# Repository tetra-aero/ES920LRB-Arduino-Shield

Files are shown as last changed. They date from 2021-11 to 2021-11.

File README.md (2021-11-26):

# ES920LRB-Arduino-Shield
Arduino Shield for ES920LRB (EASEL), Private LoRa module
- https://easel5.com/service/products-information/products/wireless-module/es920lr2/
- https://easel5.com/documents/files/ES920LR2%E3%83%87%E3%83%BC%E3%82%BF%E3%82%B7%E3%83%BC%E3%83%88_1.04.pdf
- https://easel5.com/documents/files/ES920LRB_BASE%E5%9F%BA%E6%9D%BF%E5%AF%B8%E6%B3%95%E5%9B%B3.pdf

### Ref.
1. https://ambidata.io/samples/network/lora-2/
2. https://qiita.com/nbizyc/items/6f2346ffbe005a5345e9
3. https://github.com/AmbientDataInc/LoRa-rssi-measure

## Schematic, PCB
- Arduino UNO
    - https://github.com/tetra-aero/ES920LRB-Arduino-Shield/tree/main/ES920LRB-Arduino_Uno-Shield
- ESP32 (not shield)
    - https://github.com/tetra-aero/ES920LRB-Arduino-Shield/tree/main/ES920LRB-ESP32

## Firmware
- Arduino UNO, PlatformIO
    - https://github.com/tetra-aero/ES920LRB-Arduino-Shield/tree/main/ES920LRB-Arduino_Uno-Shield/ES920LR-Arduino-PIO
- ESP32, PlatformIO
    - https://github.com/tetra-aero/ES920LRB-Arduino-Shield/tree/main/ES920LRB-ESP32/ESP920LR-Coordinator-ESP32-PIO
    - https://github.com/tetra-aero/ES920LRB-Arduino-Shield/tree/main/ES920LRB-ESP32/ESP920LR-End-device-ESP32-PIO

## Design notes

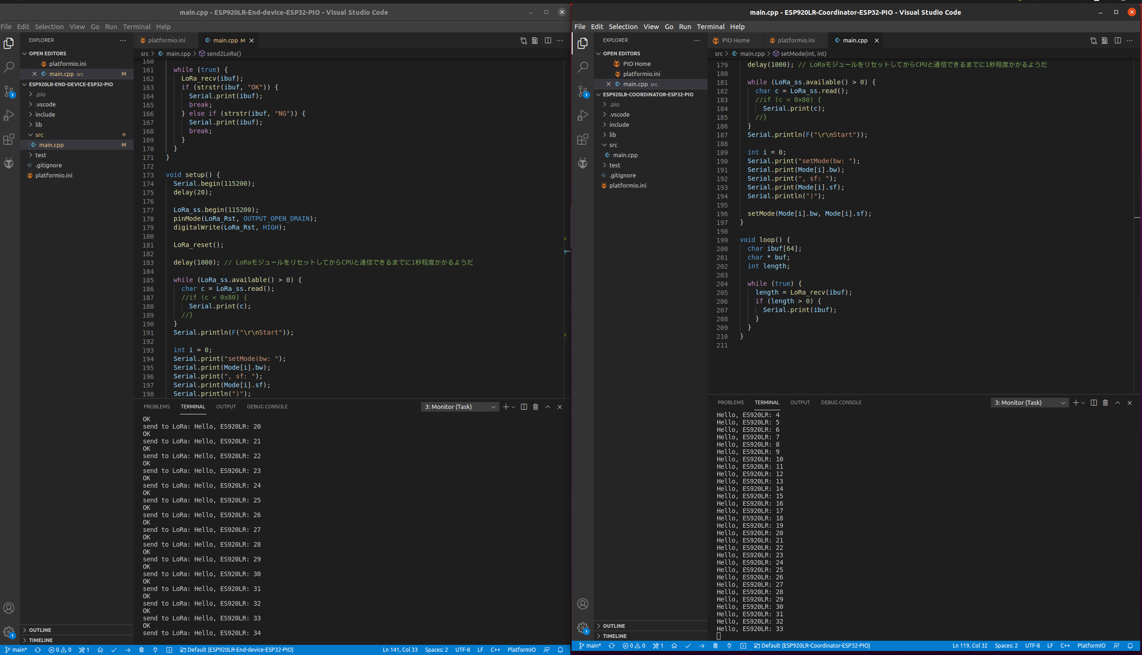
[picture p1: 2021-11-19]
document/211120_esp32_count_success.png

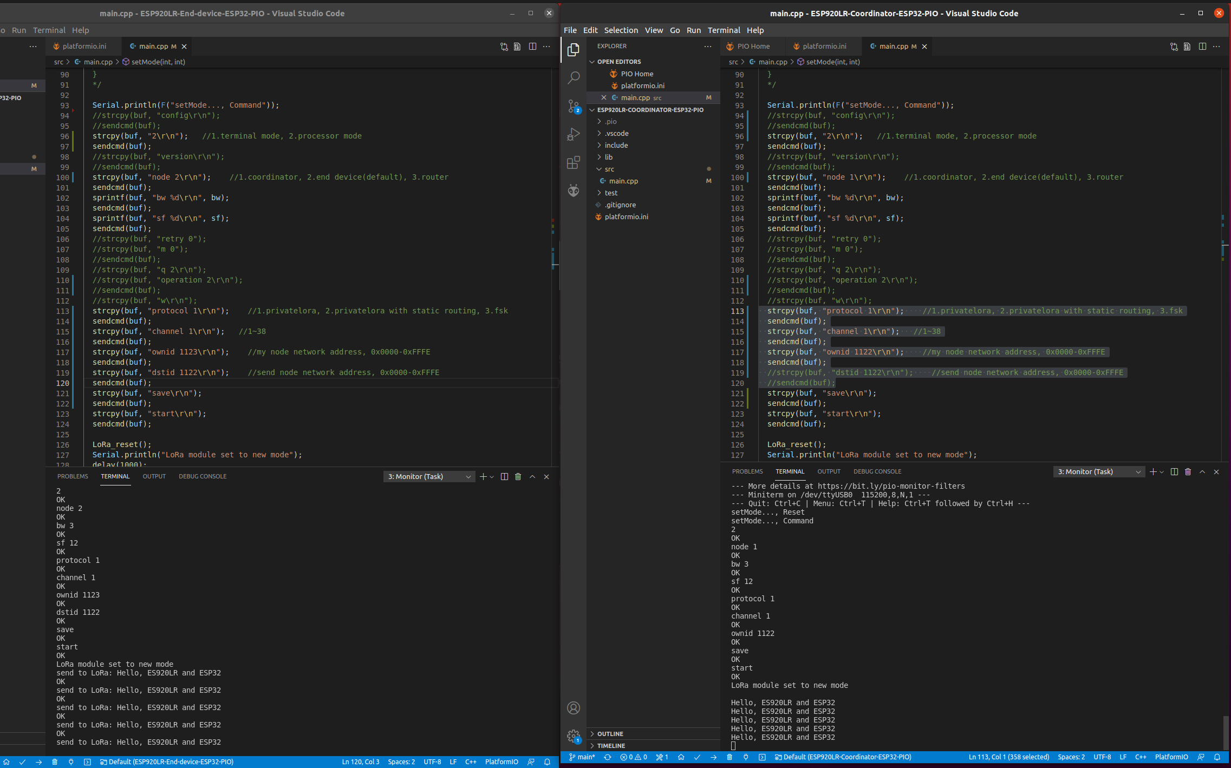
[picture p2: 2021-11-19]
document/211120_esp32_transmission_success.png

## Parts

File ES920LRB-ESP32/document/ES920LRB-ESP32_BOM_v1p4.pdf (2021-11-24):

ES920LRB-ESP32_BOM_v1p4

Source:
Date:
Tool:
Generator:
Component Count:

Collated Components:

Item
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
/home/chiya/JetsonWorks/ES920LRB-Arduino-Shield/ES920LRB-ESP32/ES920LRB-ESP32.sch Wed 24 Nov 2021 08:32:15 PM JST
Eeschema 5.1.9-73d0e3b20d~88~ubuntu20.04.1 /usr/share/kicad/plugins/bom_csv_grouped_by_value.py
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
Reference(s) | Value | LibPart
C1, C2 | 10uF | Device:C
H1, H2, H3, H4 | MountingHole | Mechanical:MountingHole
J1, J2 | Conn_01x19_Female Connector:Conn_01x19_Female
J3, J4 | Conn_01x13_Female Connector:Conn_01x13_Female
L1 | Logo | teTra:Logo
M1 | ES920LR2B | teTra:ES920LR2B
R1, R2, R3, R4, R5, R6 10k | Device:R
U1 | ESP32-DEVKITC-32D ESP32_32D_module:ESP32-DEVKITC-32D

Footprint | Datasheet | Field4
Capacitor_THT:C_Rect_L4.0mm_W2.5mm_P2.50mm | ~
MountingHole:MountingHole_3.2mm_M3 | ~
Connector_PinHeader_2.54mm:PinHeader_1x19_P2.54mm_Vertical | ~
Connector_PinHeader_2.54mm:PinHeader_1x13_P2.54mm_Vertical | ~
teTra:teTra-logo
teTra:ES92LR2B
Resistor_THT:R_Axial_DIN0207_L6.3mm_D2.5mm_P7.62mm_Horizontal ~
MODULE_ESP32-DEVKITC-32D | Espressif Systems | 4

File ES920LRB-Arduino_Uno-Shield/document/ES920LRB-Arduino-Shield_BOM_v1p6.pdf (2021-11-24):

ES920LRB-Arduino-Shield_BOM_v1p6

Source:
Date:
Tool:
Generator:
Component Count:

Collated Components:

Item
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
/home/chiya/JetsonWorks/ES920LRB-Arduino-Shield/ES920LRB-Arduino-Shield/ES920LRB-Arduino-Shield.sch Wed 24 Nov 2021 06:48:10 PM JST
Eeschema 5.1.9-73d0e3b20d~88~ubuntu20.04.1 /usr/share/kicad/plugins/bom_csv_grouped_by_value.py
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
Reference(s) | Value | LibPart
C1 | 10uF | Device:C
J1 | Conn_01x10_Female | Connector:Conn_01x10_Female
J2 | Conn_01x12_Female | Connector:Conn_01x12_Female
JP1, JP2, JP3, JP4, JP5, JP6 | SolderJumper_2_Open Jumper:SolderJumper_2_Open
L1 | Logo | teTra:Logo
M1 | ES920LR2B | teTra:ES920LR2B
P1 | Power | Connector_Generic:Conn_01x08
P2 | Analog | Connector_Generic:Conn_01x06
P3 | Digital | Connector_Generic:Conn_01x10
P4 | Digital | Connector_Generic:Conn_01x08
P5, P6, P7, P8 | CONN_01X01 | Connector_Generic:Conn_01x01
Q1, Q2, Q3, Q4 | BSS138 | add_lib2:BSS138
R1, R2, R3, R4, R5, R6, R7, R8, R9, R10 10k | Device:R

Footprint
Capacitor_THT:C_Rect_L4.0mm_W2.5mm_P2.50mm Connector_PinHeader_2.54mm:PinHeader_1x10_P2.54mm_Vertical Connector_PinHeader_2.54mm:PinHeader_1x12_P2.54mm_Vertical Jumper:SolderJumper-2_P1.3mm_Open_Pad1.0x1.5mm teTra:teTra-logo
teTra:ES92LR2B
Socket_Arduino_Uno:Socket_Strip_Arduino_1x08 Socket_Arduino_Uno:Socket_Strip_Arduino_1x06 Socket_Arduino_Uno:Socket_Strip_Arduino_1x10 Socket_Arduino_Uno:Socket_Strip_Arduino_1x08 Socket_Arduino_Uno:Arduino_1pin
Package_TO_SOT_SMD:SOT-23
Resistor_THT:R_Axial_DIN0207_L6.3mm_D2.5mm_P2.54mm_Vertical

Datasheet
~
~
~
~

Replace 1.27mm pitch, 3.0mm height, pin socket x2

https://www.onsemi.com/pub/Collateral/BSS138-D.PDF ~

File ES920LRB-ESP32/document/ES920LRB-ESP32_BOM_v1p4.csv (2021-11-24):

Source: | /home/chiya/JetsonWorks/ES920LRB-Arduino-Shield/ES920LRB-ESP32/ES920LRB-ESP32.sch
Date: | Wed 24 Nov 2021 08:32:15 PM JST
Tool: | Eeschema 5.1.9-73d0e3b20d~88~ubuntu20.04.1
Generator: | /usr/share/kicad/plugins/bom_csv_grouped_by_value.py
Component Count: | 19
Individual Components:
Item | Qty | Reference(s) | Value | LibPart | Footprint | Datasheet | Field4
 |  | C1 | 10uF | Device:C | Capacitor_THT:C_Rect_L4.0mm_W2.5mm_P2.50mm | ~
 |  | C2 | 10uF | Device:C | Capacitor_THT:C_Rect_L4.0mm_W2.5mm_P2.50mm | ~
 |  | H1 | MountingHole | Mechanical:MountingHole | MountingHole:MountingHole_3.2mm_M3 | ~
 |  | H2 | MountingHole | Mechanical:MountingHole | MountingHole:MountingHole_3.2mm_M3 | ~
 |  | H3 | MountingHole | Mechanical:MountingHole | MountingHole:MountingHole_3.2mm_M3 | ~
 |  | H4 | MountingHole | Mechanical:MountingHole | MountingHole:MountingHole_3.2mm_M3 | ~
 |  | J1 | Conn_01x19_Female | Connector:Conn_01x19_Female | Connector_PinHeader_2.54mm:PinHeader_1x19_P2.54mm_Vertical | ~
 |  | J2 | Conn_01x19_Female | Connector:Conn_01x19_Female | Connector_PinHeader_2.54mm:PinHeader_1x19_P2.54mm_Vertical | ~
 |  | J3 | Conn_01x13_Female | Connector:Conn_01x13_Female | Connector_PinHeader_2.54mm:PinHeader_1x13_P2.54mm_Vertical | ~
 |  | J4 | Conn_01x13_Female | Connector:Conn_01x13_Female | Connector_PinHeader_2.54mm:PinHeader_1x13_P2.54mm_Vertical | ~
 |  | L1 | Logo | teTra:Logo | teTra:teTra-logo
 |  | M1 | ES920LR2B | teTra:ES920LR2B | teTra:ES92LR2B
 |  | R1 | 10k | Device:R | Resistor_THT:R_Axial_DIN0207_L6.3mm_D2.5mm_P7.62mm_Horizontal | ~
 |  | R2 | 10k | Device:R | Resistor_THT:R_Axial_DIN0207_L6.3mm_D2.5mm_P7.62mm_Horizontal | ~
 |  | R3 | 10k | Device:R | Resistor_THT:R_Axial_DIN0207_L6.3mm_D2.5mm_P7.62mm_Horizontal | ~
 |  | R4 | 10k | Device:R | Resistor_THT:R_Axial_DIN0207_L6.3mm_D2.5mm_P7.62mm_Horizontal | ~
 |  | R5 | 10k | Device:R | Resistor_THT:R_Axial_DIN0207_L6.3mm_D2.5mm_P7.62mm_Horizontal | ~
 |  | R6 | 10k | Device:R | Resistor_THT:R_Axial_DIN0207_L6.3mm_D2.5mm_P7.62mm_Horizontal | ~
 |  | U1 | ESP32-DEVKITC-32D | ESP32_32D_module:ESP32-DEVKITC-32D | MODULE_ESP32-DEVKITC-32D | Espressif Systems | 4
Collated Components:
Item | Qty | Reference(s) | Value | LibPart | Footprint | Datasheet | Field4
1 | 2 | C1, C2 | 10uF | Device:C | Capacitor_THT:C_Rect_L4.0mm_W2.5mm_P2.50mm | ~
2 | 4 | H1, H2, H3, H4 | MountingHole | Mechanical:MountingHole | MountingHole:MountingHole_3.2mm_M3 | ~
3 | 2 | J1, J2 | Conn_01x19_Female | Connector:Conn_01x19_Female | Connector_PinHeader_2.54mm:PinHeader_1x19_P2.54mm_Vertical | ~
4 | 2 | J3, J4 | Conn_01x13_Female | Connector:Conn_01x13_Female | Connector_PinHeader_2.54mm:PinHeader_1x13_P2.54mm_Vertical | ~
5 | 1 | L1 | Logo | teTra:Logo | teTra:teTra-logo
6 | 1 | M1 | ES920LR2B | teTra:ES920LR2B | teTra:ES92LR2B
7 | 6 | R1, R2, R3, R4, R5, R6 | 10k | Device:R | Resistor_THT:R_Axial_DIN0207_L6.3mm_D2.5mm_P7.62mm_Horizontal | ~
8 | 1 | U1 | ESP32-DEVKITC-32D | ESP32_32D_module:ESP32-DEVKITC-32D | MODULE_ESP32-DEVKITC-32D | Espressif Systems | 4

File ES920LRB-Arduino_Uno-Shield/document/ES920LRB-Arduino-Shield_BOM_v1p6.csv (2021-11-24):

Source: | /home/chiya/JetsonWorks/ES920LRB-Arduino-Shield/ES920LRB-Arduino-Shield/ES920LRB-Arduino-Shield.sch
Date: | Wed 24 Nov 2021 06:48:10 PM JST
Tool: | Eeschema 5.1.9-73d0e3b20d~88~ubuntu20.04.1
Generator: | /usr/share/kicad/plugins/bom_csv_grouped_by_value.py
Component Count: | 33
Individual Components:
Item | Qty | Reference(s) | Value | LibPart | Footprint | Datasheet
 |  | C1 | 10uF | Device:C | Capacitor_THT:C_Rect_L4.0mm_W2.5mm_P2.50mm | ~
 |  | J1 | Conn_01x10_Female | Connector:Conn_01x10_Female | Connector_PinHeader_2.54mm:PinHeader_1x10_P2.54mm_Vertical | ~
 |  | J2 | Conn_01x12_Female | Connector:Conn_01x12_Female | Connector_PinHeader_2.54mm:PinHeader_1x12_P2.54mm_Vertical | ~
 |  | JP1 | SolderJumper_2_Open | Jumper:SolderJumper_2_Open | Jumper:SolderJumper-2_P1.3mm_Open_Pad1.0x1.5mm | ~
 |  | JP2 | SolderJumper_2_Open | Jumper:SolderJumper_2_Open | Jumper:SolderJumper-2_P1.3mm_Open_Pad1.0x1.5mm | ~
 |  | JP3 | SolderJumper_2_Open | Jumper:SolderJumper_2_Open | Jumper:SolderJumper-2_P1.3mm_Open_Pad1.0x1.5mm | ~
 |  | JP4 | SolderJumper_2_Open | Jumper:SolderJumper_2_Open | Jumper:SolderJumper-2_P1.3mm_Open_Pad1.0x1.5mm | ~
 |  | JP5 | SolderJumper_2_Open | Jumper:SolderJumper_2_Open | Jumper:SolderJumper-2_P1.3mm_Open_Pad1.0x1.5mm | ~
 |  | JP6 | SolderJumper_2_Open | Jumper:SolderJumper_2_Open | Jumper:SolderJumper-2_P1.3mm_Open_Pad1.0x1.5mm | ~
 |  | L1 | Logo | teTra:Logo | teTra:teTra-logo
 |  | M1 | ES920LR2B | teTra:ES920LR2B | teTra:ES92LR2B
 |  | P1 | Power | Connector_Generic:Conn_01x08 | Socket_Arduino_Uno:Socket_Strip_Arduino_1x08
 |  | P2 | Analog | Connector_Generic:Conn_01x06 | Socket_Arduino_Uno:Socket_Strip_Arduino_1x06
 |  | P3 | Digital | Connector_Generic:Conn_01x10 | Socket_Arduino_Uno:Socket_Strip_Arduino_1x10
 |  | P4 | Digital | Connector_Generic:Conn_01x08 | Socket_Arduino_Uno:Socket_Strip_Arduino_1x08
 |  | P5 | CONN_01X01 | Connector_Generic:Conn_01x01 | Socket_Arduino_Uno:Arduino_1pin
 |  | P6 | CONN_01X01 | Connector_Generic:Conn_01x01 | Socket_Arduino_Uno:Arduino_1pin
 |  | P7 | CONN_01X01 | Connector_Generic:Conn_01x01 | Socket_Arduino_Uno:Arduino_1pin
 |  | P8 | CONN_01X01 | Connector_Generic:Conn_01x01 | Socket_Arduino_Uno:Arduino_1pin
 |  | Q1 | BSS138 | add_lib2:BSS138 | Package_TO_SOT_SMD:SOT-23 | https://www.onsemi.com/pub/Collateral/BSS138-D.PDF
 |  | Q2 | BSS138 | add_lib2:BSS138 | Package_TO_SOT_SMD:SOT-23 | https://www.onsemi.com/pub/Collateral/BSS138-D.PDF
 |  | Q3 | BSS138 | add_lib2:BSS138 | Package_TO_SOT_SMD:SOT-23 | https://www.onsemi.com/pub/Collateral/BSS138-D.PDF
 |  | Q4 | BSS138 | add_lib2:BSS138 | Package_TO_SOT_SMD:SOT-23 | https://www.onsemi.com/pub/Collateral/BSS138-D.PDF
 |  | R1 | 10k | Device:R | Resistor_THT:R_Axial_DIN0207_L6.3mm_D2.5mm_P2.54mm_Vertical | ~
 |  | R2 | 10k | Device:R | Resistor_THT:R_Axial_DIN0207_L6.3mm_D2.5mm_P2.54mm_Vertical | ~
 |  | R3 | 10k | Device:R | Resistor_THT:R_Axial_DIN0207_L6.3mm_D2.5mm_P2.54mm_Vertical | ~
 |  | R4 | 10k | Device:R | Resistor_THT:R_Axial_DIN0207_L6.3mm_D2.5mm_P2.54mm_Vertical | ~
 |  | R5 | 10k | Device:R | Resistor_THT:R_Axial_DIN0207_L6.3mm_D2.5mm_P2.54mm_Vertical | ~
 |  | R6 | 10k | Device:R | Resistor_THT:R_Axial_DIN0207_L6.3mm_D2.5mm_P2.54mm_Vertical | ~
 |  | R7 | 10k | Device:R | Resistor_THT:R_Axial_DIN0207_L6.3mm_D2.5mm_P2.54mm_Vertical | ~
 |  | R8 | 10k | Device:R | Resistor_THT:R_Axial_DIN0207_L6.3mm_D2.5mm_P2.54mm_Vertical | ~
 |  | R9 | 10k | Device:R | Resistor_THT:R_Axial_DIN0207_L6.3mm_D2.5mm_P2.54mm_Vertical | ~
 |  | R10 | 10k | Device:R | Resistor_THT:R_Axial_DIN0207_L6.3mm_D2.5mm_P2.54mm_Vertical | ~
Collated Components:
Item | Qty | Reference(s) | Value | LibPart | Footprint | Datasheet
1 | 1 | C1 | 10uF | Device:C | Capacitor_THT:C_Rect_L4.0mm_W2.5mm_P2.50mm | ~
2 | 1 | J1 | Conn_01x10_Female | Connector:Conn_01x10_Female | Connector_PinHeader_2.54mm:PinHeader_1x10_P2.54mm_Vertical | ~
3 | 1 | J2 | Conn_01x12_Female | Connector:Conn_01x12_Female | Connector_PinHeader_2.54mm:PinHeader_1x12_P2.54mm_Vertical | ~
4 | 6 | JP1, JP2, JP3, JP4, JP5, JP6 | SolderJumper_2_Open | Jumper:SolderJumper_2_Open | Jumper:SolderJumper-2_P1.3mm_Open_Pad1.0x1.5mm | ~
5 | 1 | L1 | Logo | teTra:Logo | teTra:teTra-logo
6 | 1 | M1 | ES920LR2B | teTra:ES920LR2B | teTra:ES92LR2B
7 | 1 | P1 | Power | Connector_Generic:Conn_01x08 | Socket_Arduino_Uno:Socket_Strip_Arduino_1x08
8 | 1 | P2 | Analog | Connector_Generic:Conn_01x06 | Socket_Arduino_Uno:Socket_Strip_Arduino_1x06
9 | 1 | P3 | Digital | Connector_Generic:Conn_01x10 | Socket_Arduino_Uno:Socket_Strip_Arduino_1x10
10 | 1 | P4 | Digital | Connector_Generic:Conn_01x08 | Socket_Arduino_Uno:Socket_Strip_Arduino_1x08
11 | 4 | P5, P6, P7, P8 | CONN_01X01 | Connector_Generic:Conn_01x01 | Socket_Arduino_Uno:Arduino_1pin
12 | 4 | Q1, Q2, Q3, Q4 | BSS138 | add_lib2:BSS138 | Package_TO_SOT_SMD:SOT-23 | https://www.onsemi.com/pub/Collateral/BSS138-D.PDF
13 | 10 | R1, R2, R3, R4, R5, R6, R7, R8, R9, R10 | 10k | Device:R | Resistor_THT:R_Axial_DIN0207_L6.3mm_D2.5mm_P2.54mm_Vertical | ~

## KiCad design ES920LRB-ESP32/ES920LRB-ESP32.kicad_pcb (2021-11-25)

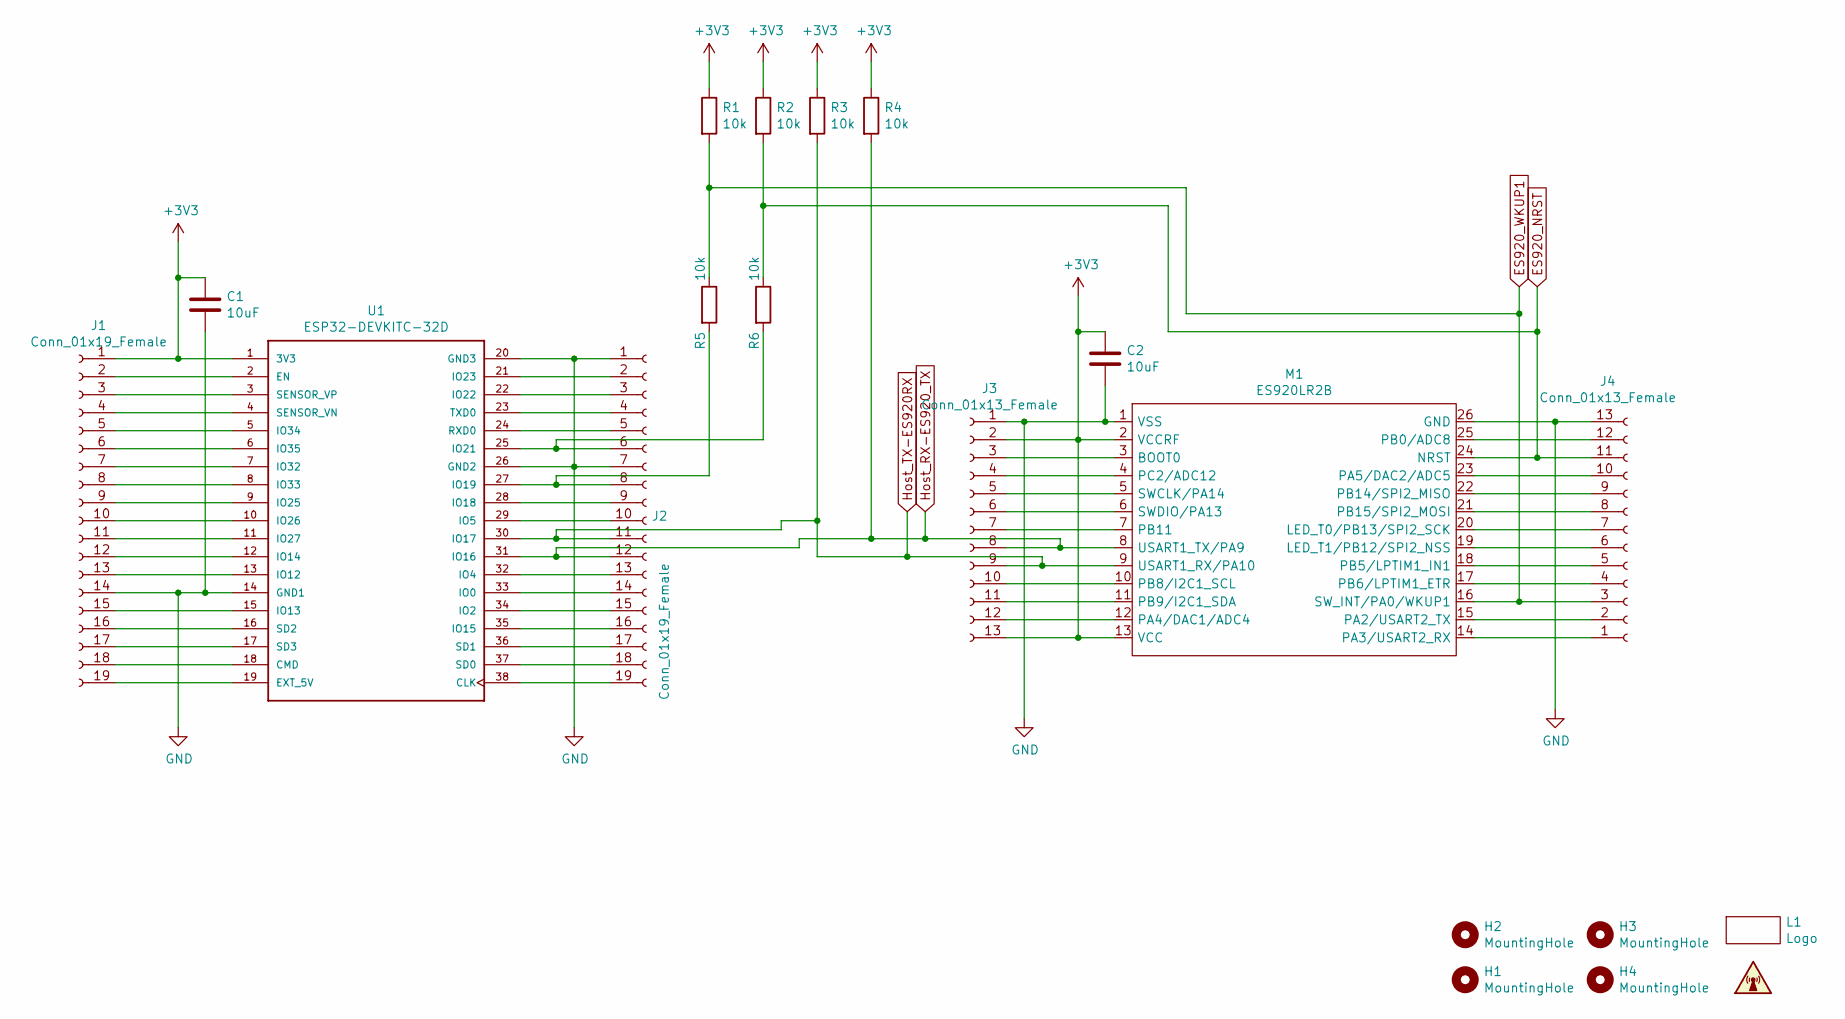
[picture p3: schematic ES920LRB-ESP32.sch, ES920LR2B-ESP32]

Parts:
C1, C2: 10uF; C_Rect_L4.0mm_W2.5mm_P2.50mm
H1, H2, H3, H4: MountingHole; MountingHole_3.2mm_M3
J1, J2: Conn_01x19_Female; PinHeader_1x19_P2.54mm_Vertical
J3, J4: Conn_01x13_Female; PinHeader_1x13_P2.54mm_Vertical
L1: Logo; teTra-logo
M1: ES920LR2B; ES92LR2B
R1, R2, R3, R4, R5, R6: 10k; R_Axial_DIN0207_L6.3mm_D2.5mm_P7.62mm_Horizontal
U1: ESP32-DEVKITC-32D; MODULE_ESP32-DEVKITC-32D

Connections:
+3V3: C1.1, C2.1, J1.1, J3.2, J3.13, M1.2 (VCCRF), M1.13 (VCC), R1.1, R2.1, R3.1, R4.1, U1.1 (3V3)
ES920_NRST: J4.11, M1.24 (NRST), R2.2, R6.1
ES920_WKUP1: J4.3, M1.16 (SW_INT/PA0/WKUP1), R1.2, R5.1
GND: C1.2, C2.2, J1.14, J2.1, J2.7, J3.1, J4.13, M1.1 (VSS), M1.26 (GND), U1.14 (GND1), U1.20 (GND3), U1.26 (GND2)
Host_RX-ES920_TX: J2.12, J3.8, M1.8 (USART1_TX/PA9), R4.2, U1.31 (IO16)
Host_TX-ES920RX: J2.11, J3.9, M1.9 (USART1_RX/PA10), R3.2, U1.30 (IO17)
unnamed: J1.2, U1.2 (EN)
unnamed: J1.3, U1.3 (SENSOR_VP)
unnamed: J1.4, U1.4 (SENSOR_VN)
unnamed: J1.5, U1.5 (IO34)
unnamed: J1.6, U1.6 (IO35)
unnamed: J1.7, U1.7 (IO32)
unnamed: J1.8, U1.8 (IO33)
unnamed: J1.9, U1.9 (IO25)
unnamed: J1.10, U1.10 (IO26)
unnamed: J1.11, U1.11 (IO27)
unnamed: J1.12, U1.12 (IO14)
unnamed: J1.13, U1.13 (IO12)
unnamed: J1.15, U1.15 (IO13)
unnamed: J1.16, U1.16 (SD2)
unnamed: J1.17, U1.17 (SD3)
unnamed: J1.18, U1.18 (CMD)
unnamed: J1.19, U1.19 (EXT_5V)
unnamed: J2.2, U1.21 (IO23)
unnamed: J2.3, U1.22 (IO22)
unnamed: J2.4, U1.23 (TXD0)
unnamed: J2.5, U1.24 (RXD0)
unnamed: J2.6, R6.2, U1.25 (IO21)
unnamed: J2.8, R5.2, U1.27 (IO19)
unnamed: J2.9, U1.28 (IO18)
unnamed: J2.10, U1.29 (IO5)
unnamed: J2.13, U1.32 (IO4)
unnamed: J2.14, U1.33 (IO0)
unnamed: J2.15, U1.34 (IO2)
unnamed: J2.16, U1.35 (IO15)
unnamed: J2.17, U1.36 (SD1)
unnamed: J2.18, U1.37 (SD0)
unnamed: J2.19, U1.38 (CLK)
unnamed: J3.3, M1.3 (BOOT0)
unnamed: J3.4, M1.4 (PC2/ADC12)
unnamed: J3.5, M1.5 (SWCLK/PA14)
unnamed: J3.6, M1.6 (SWDIO/PA13)
unnamed: J3.7, M1.7 (PB11)
unnamed: J3.10, M1.10 (PB8/I2C1_SCL)
unnamed: J3.11, M1.11 (PB9/I2C1_SDA)
unnamed: J3.12, M1.12 (PA4/DAC1/ADC4)
unnamed: J4.1, M1.14 (PA3/USART2_RX)
unnamed: J4.2, M1.15 (PA2/USART2_TX)
unnamed: J4.4, M1.17 (PB6/LPTIM1_ETR)
unnamed: J4.5, M1.18 (PB5/LPTIM1_IN1)
unnamed: J4.6, M1.19 (LED_T1/PB12/SPI2_NSS)
unnamed: J4.7, M1.20 (LED_T0/PB13/SPI2_SCK)
unnamed: J4.8, M1.21 (PB15/SPI2_MOSI)
unnamed: J4.9, M1.22 (PB14/SPI2_MISO)
unnamed: J4.10, M1.23 (PA5/DAC2/ADC5)
unnamed: J4.12, M1.25 (PB0/ADC8)

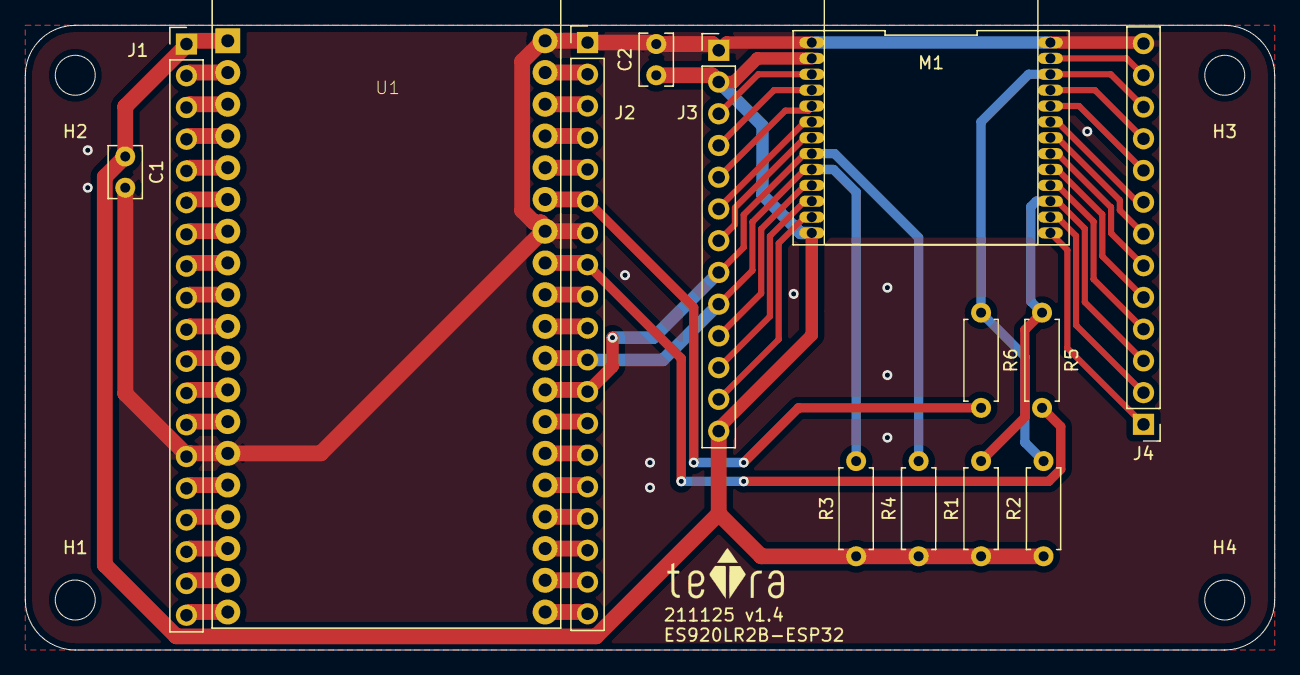
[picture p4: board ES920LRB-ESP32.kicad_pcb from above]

Board: 2 copper layers, 100.0 x 50.0 mm, 19 parts (0 on the bottom side), 56 nets.

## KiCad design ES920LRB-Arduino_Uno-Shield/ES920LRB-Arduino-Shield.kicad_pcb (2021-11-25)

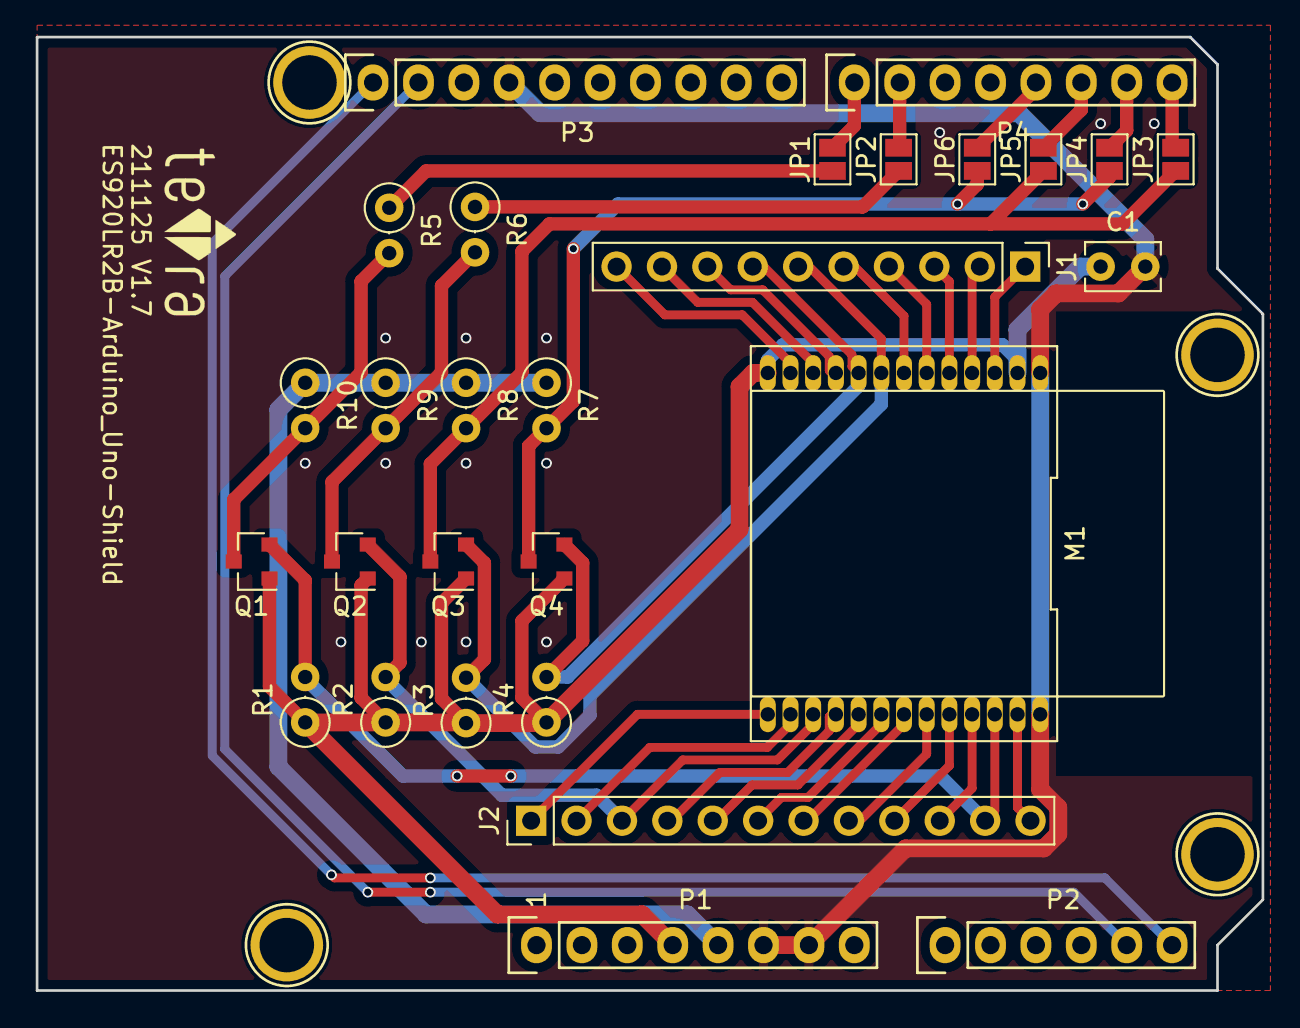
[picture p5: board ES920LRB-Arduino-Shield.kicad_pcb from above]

Board: 2 copper layers, 68.6 x 53.3 mm, 33 parts (0 on the bottom side), 39 nets.

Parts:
C1: 10uF; C_Rect_L4.0mm_W2.5mm_P2.50mm
J1: Conn_01x10_Female; PinHeader_1x10_P2.54mm_Vertical
J2: Conn_01x12_Female; PinHeader_1x12_P2.54mm_Vertical
JP1, JP2, JP3, JP4, JP5, JP6: SolderJumper_2_Open; SolderJumper-2_P1.3mm_Open_Pad1.0x1.5mm
L1: Logo; teTra-logo
M1: ES920LR2B; ES92LR2B
P1: Power; Socket_Strip_Arduino_1x08
P2: Analog; Socket_Strip_Arduino_1x06
P3: Digital; Socket_Strip_Arduino_1x10
P4: Digital; Socket_Strip_Arduino_1x08
P5, P6, P7, P8: CONN_01X01; Arduino_1pin
Q1, Q2, Q3, Q4: BSS138; SOT-23
R1, R2, R3, R4, R5, R6, R7, R8, R9, R10: 10k; R_Axial_DIN0207_L6.3mm_D2.5mm_P2.54mm_Vertical

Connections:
+3V3: C1.1, M1.2, M1.13, P1.4, Q1.1, Q2.1, Q3.1, Q4.1, R1.1, R2.1, R3.1, R4.1
+5V: P1.5, R7.1, R8.1, R9.1, R10.1
/0(Rx): JP3.2, P4.8
/1(Tx): JP4.2, P4.7
/2: JP5.2, P4.6
/3(**): JP6.2, P4.5
/6(**): JP2.2, P4.2
/7: JP1.2, P4.1
/A4(SDA): P2.5, P3.2
/A5(SCL): P2.6, P3.1
GND: C1.2, M1.1, M1.26, P1.6, P1.7, P3.4
unnamed: J1.1, M1.3
unnamed: J1.2, M1.4
unnamed: J1.3, M1.5
unnamed: J1.4, M1.6
unnamed: J1.5, M1.7
unnamed: J1.6, M1.8, Q3.2, R3.2
unnamed: J1.7, M1.9, Q4.2, R4.2
unnamed: J1.8, M1.10
unnamed: J1.9, M1.11
unnamed: J1.10, M1.12
unnamed: J2.1, M1.14
unnamed: J2.2, M1.15
unnamed: J2.3, M1.16, Q2.2, R2.2
unnamed: J2.4, M1.17
unnamed: J2.5, M1.18
unnamed: J2.6, M1.19
unnamed: J2.7, M1.20
unnamed: J2.8, M1.21
unnamed: J2.9, M1.22
unnamed: J2.10, M1.23
unnamed: J2.11, M1.24, Q1.2, R1.2
unnamed: J2.12, M1.25
unnamed: JP1.1, R5.1
unnamed: JP2.1, R6.1
unnamed: JP3.1, JP5.1, Q3.3, R8.2
unnamed: JP4.1, JP6.1, Q4.3, R7.2
unnamed: Q1.3, R5.2, R10.2
unnamed: Q2.3, R6.2, R9.2

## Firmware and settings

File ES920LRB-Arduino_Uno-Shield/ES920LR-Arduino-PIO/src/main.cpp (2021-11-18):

#include <Arduino.h>
//#include <SoftwareSerial.h>
#include <string.h>

#if defined(ESP32)
// for ESP32 devkit v4
static const int LED_BUILTIN  = 2;
#else
//static const int LED_BUILTIN = 13;
#endif

static const int LoRa_Rst = 21;
//static const int LoRa_RX = 2, LoRa_TX = 3;
//SoftwareSerial LoRa_ss(LoRa_RX, LoRa_TX);
HardwareSerial LoRa_ss(2);  //ESP32, RX2: GPIO16, TX2: GPIO17

void LoRa_reset(void) {
  digitalWrite(LoRa_Rst, LOW);
  delay(100);
  digitalWrite(LoRa_Rst, HIGH);
}

int LoRa_recv(char *buf) {
  char *start = buf;

  while (true) {
    delay(0);
    while (LoRa_ss.available() > 0) {
      *buf++ = LoRa_ss.read();
      if (*(buf-2) == '\r' && *(buf-1) == '\n') {
        *buf = '\0';
        return (buf - start);
      }
    }
  }
}

int LoRa_send(char * msg) {
  char *start = msg;
  while (*msg != '\0') {
      LoRa_ss.write(*msg++);
  }
  return (msg - start);
}

#define NMODE 24
 
struct mode {
  int bw;
  int sf;
  int timeout;
};

struct mode Mode[NMODE] = {
  {3, 12, 5}, {3, 11, 5}, {3, 10, 4}, {3, 9, 3}, {3, 8, 2}, {3, 7, 2},
  {4, 12, 5}, {4, 11, 4}, {4, 10, 3}, {4, 9, 3}, {4, 8, 2}, {4, 7, 2},
  {5, 12, 4}, {5, 11, 3}, {5, 10, 2}, {5, 9, 2}, {5, 8, 2}, {5, 7, 2},
  {6, 12, 3}, {6, 11, 3}, {6, 10, 2}, {6, 9, 2}, {6, 8, 2}, {6, 7, 2},
};

int sendcmd(char *cmd) {
  char buf[64];

  Serial.print(cmd);
  LoRa_send(cmd);

  while (true) {
    LoRa_recv(buf);
    if (strstr(buf, "OK")) {
      Serial.print(buf);
      return true;
    } else if (strstr(buf, "NG")) {
      Serial.print(buf);
      return false;
    }
  }
}

void setMode(int bw, int sf) {
  char buf[64];

  Serial.println(F("setMode..."));
  //strcpy(buf, "config\r\n");
  //strcpy(buf, "operation\r\n");
  //LoRa_send(buf);
  //sendcmd(buf);
  //delay(200);
  LoRa_reset();
  delay(1500);

  Serial.println(F("setMode..., Reset"));
  /*
  while (true) {
    LoRa_recv(buf);
    Serial.print(buf);
    if (strstr(buf, "Mode")) {
      Serial.print(buf);
      break;
    }
  }
  */

  Serial.println(F("setMode..., Command"));
  strcpy(buf, "2\r\n");
  sendcmd(buf);
  //strcpy(buf, "config\r\n");
  //sendcmd(buf);
  //strcpy(buf, "version\r\n");
  //sendcmd(buf);
  sprintf(buf, "bw %d\r\n", bw);
  sendcmd(buf);
  sprintf(buf, "sf %d\r\n", sf);
  sendcmd(buf);
  //strcpy(buf, "retry 0");
  //strcpy(buf, "m 0");
  //sendcmd(buf);
  //strcpy(buf, "q 2\r\n");
  strcpy(buf, "operation 2\r\n");
  sendcmd(buf);
  //strcpy(buf, "w\r\n");
  //strcpy(buf, "save\r\n");
  //sendcmd(buf);
  //strcpy(buf, "start\r\n");
  //sendcmd(buf);

  LoRa_reset();
  Serial.println("LoRa module set to new mode");
  delay(1000);
}

void send2LoRa() {
  char obuf[64], ibuf[64];
  char * buf;
  unsigned long t;

  //strcpy(obuf, "loc=(");
  //strcat(obuf, "Hello, ES920LR and Arduino\r\n");
  strcpy(obuf, "Hello, ES920LR and ESP32\r\n");

  digitalWrite(LED_BUILTIN, HIGH);

  int i = 0;
  Serial.print("setMode(bw: ");
  Serial.print(Mode[i].bw);
  Serial.print(", sf: ");
  Serial.print(Mode[i].sf);
  Serial.println(")");

  setMode(Mode[i].bw, Mode[i].sf);

  t = millis();
  delay(500);

  Serial.print("send to LoRa: ");
  buf = obuf;
  Serial.print(buf);
  LoRa_send(buf);

  while (true) {
    LoRa_recv(ibuf);
    if (strstr(ibuf, "OK")) {
      Serial.print(ibuf);
      break;
    } else if (strstr(ibuf, "NG")) {
      Serial.print(ibuf);
      break;
    }
  }
/*
  if (i != 0) {
    long s;

    s = Mode[i].timeout * 1000 - (millis() - t);
    if (s > 0) {
      Serial.print("delay: ");
      Serial.println(s);
      delay(s);
    }
  }
*/
  digitalWrite(LED_BUILTIN, LOW);
}

void setup() {
  Serial.begin(115200);
  delay(20);

  pinMode(LED_BUILTIN, OUTPUT);
  digitalWrite(LED_BUILTIN, LOW);

  LoRa_ss.begin(115200);
  pinMode(LoRa_Rst, OUTPUT_OPEN_DRAIN);
  digitalWrite(LoRa_Rst, HIGH);

  LoRa_reset();

  delay(1000); // LoRaモジュールをリセットしてからCPUと通信できるまでに1秒程度かかるようだ

  while (LoRa_ss.available() > 0) {
    char c = LoRa_ss.read();
    //if (c < 0x80) {
      Serial.print(c);
    //}
  }
  Serial.println(F("\r\nStart"));
}

void loop() {
  send2LoRa();
  delay(10000);
}

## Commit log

2021-11-16 add v1.1
    add v1.1
    [ES920LRB-Arduino-Shield.kicad_pcb, ES920LRB-Arduino-Shield.sch]
2021-11-18 add v1.2
    add v1.2
    [ES920LRB-Arduino-Shield.sch]
2021-11-18 5V <---> 3V3変換が必要じゃん、add esp32 under construction
    5V <---> 3V3変換が必要じゃん、add esp32 under construction
    [ES920LRB-ESP32.kicad_pcb, ES920LRB-ESP32.sch]
2021-11-19 esp32 coordinator and end device under construction
    esp32 coordinator and end device under construction
    [ES920LRB-Arduino-Shield.kicad_pcb, ES920LRB-Arduino-Shield.sch]
2021-11-19 success esp32 communication
    success esp32 communication
2021-11-19 success esp32 count
    success esp32 count
2021-11-24 add schematica v1.3
    add schematica v1.3
    [ES920LRB-Arduino-Shield.kicad_pcb, ES920LRB-Arduino-Shield.sch, ES920LRB-ESP32.kicad_pcb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]
2021-11-24 add v1.4
    add v1.4
    [ES920LRB-Arduino-Shield.sch]
2021-11-24 add arduino uno sheild pcb
    add arduino uno sheild pcb
    [ES920LRB-Arduino-Shield-B_Cu.gbl, ES920LRB-Arduino-Shield-B_Mask.gbs, ES920LRB-Arduino-Shield-B_SilkS.gbo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]
2021-11-24 add arduino uno shield v1.6
    add arduino uno shield v1.6
    [ES920LRB-Arduino-Shield-B_Cu.gbl, ES920LRB-Arduino-Shield-B_Mask.gbs, ES920LRB-Arduino-Shield-B_SilkS.gbo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]
2021-11-24 add ES920LRB-ESP32 v1.4
    add ES920LRB-ESP32 v1.4
    [ES920LRB-ESP32-B_Cu.gbl, ES920LRB-ESP32-B_Mask.gbs, ES920LRB-ESP32-B_SilkS.gbo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]
2021-11-24 add ES920LRB-ESP32 v1.4 BOM
    add ES920LRB-ESP32 v1.4 BOM
    [ES920LRB-ESP32_BOM_v1p4.csv, ES920LRB-ESP32_BOM_v1p4.ods]
2021-11-25 order pcb v1.x
    order pcb v1.x
    [ES920LRB-Arduino-Shield-B_Cu.gbl, ES920LRB-Arduino-Shield-B_Mask.gbs, ES920LRB-Arduino-Shield-B_SilkS.gbo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]
